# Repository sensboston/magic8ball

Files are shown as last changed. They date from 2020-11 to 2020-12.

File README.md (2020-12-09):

# "Magic 8 Ball" toy project
Arduino (ESP32-based) project for digital implementation of "Magic 8 ball" toy

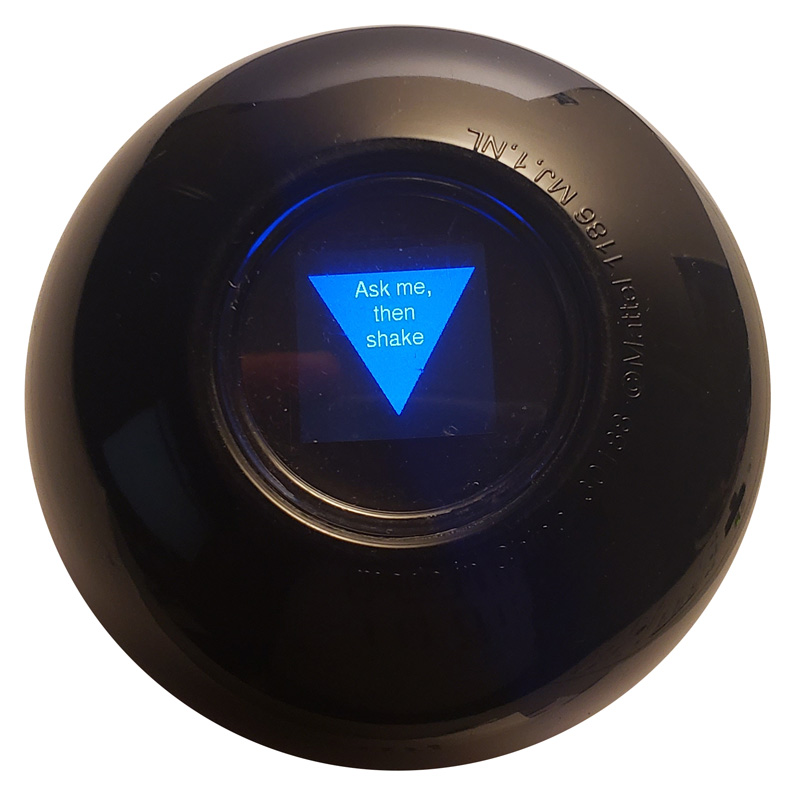
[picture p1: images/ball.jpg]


[](https://youtu.be/ifog76ZFch0)

## Features
This digital toy project offers many nice features unlike similar ones:
* multiple languages support
* synthetic voices
* realistic (or "realistic" :wink: ) animations
* gesture-based user interface
* "deep sleep" functionality (for better power consumption)

## Parts
Name | Link
------------ | -------------
**ESP32 development board** | [eBay](https://www.ebay.com/itm/Wireless-module-NodeMcu-v3-v2-ESP8266-D1MINI-Lua-WIFI-development-board-Rs4/283956013684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)
**TFT IPS Display 1.3'' 240x240** | [Amazon](https://www.amazon.com/gp/product/B088CQ4GPT/)
**DFPlayer Mini**| [eBay](https://www.ebay.com/itm/Useful-Mini-Mp3-Player-Module-DFPlayer-Micro-SD-TF-U-disk-for-Arduino-US/152513919098)
**16GB micro sdcard**| [Amazon](https://www.amazon.com/PNY-Performance-microSD-Memory-P-SDU16G4X5-MP/dp/B083VMR3PL/)
**MPU-6050 Accelerometer & Gyroscope Sensor** | [Amazon](https://www.amazon.com/Ximimark-MPU-6050-Accelerometer-Gyroscope-Converter/dp/B07M98PKT4)
**AAA battery holder** | [AliExpress](https://www.aliexpress.com/item/32719302709.html?spm=a2g0s.9042311.0.0.27424c4dsAHXA0)
**Short micro USB cable** | [eBay](https://www.ebay.com/itm/1M-Micro-USB-Extension-Charging-Data-Cable-Charger-Type-A-Male-To-Female/302277483939)
**Push button** | [Amazon](https://www.amazon.com/OFNMY-Self-Locking-Latching-Button-Switch/dp/B07NX7S9VV/)
**Original "Magic 8 ball" toy (for case)** | [Amazon](https://www.amazon.com/Mattel-Games-Magic-Ball-Retro/dp/B0149MC426/)

_Note: I believe, you can find better parts pricing on Ali/eBay etc. And I already had many of these parts before starting this project._

## Circuit
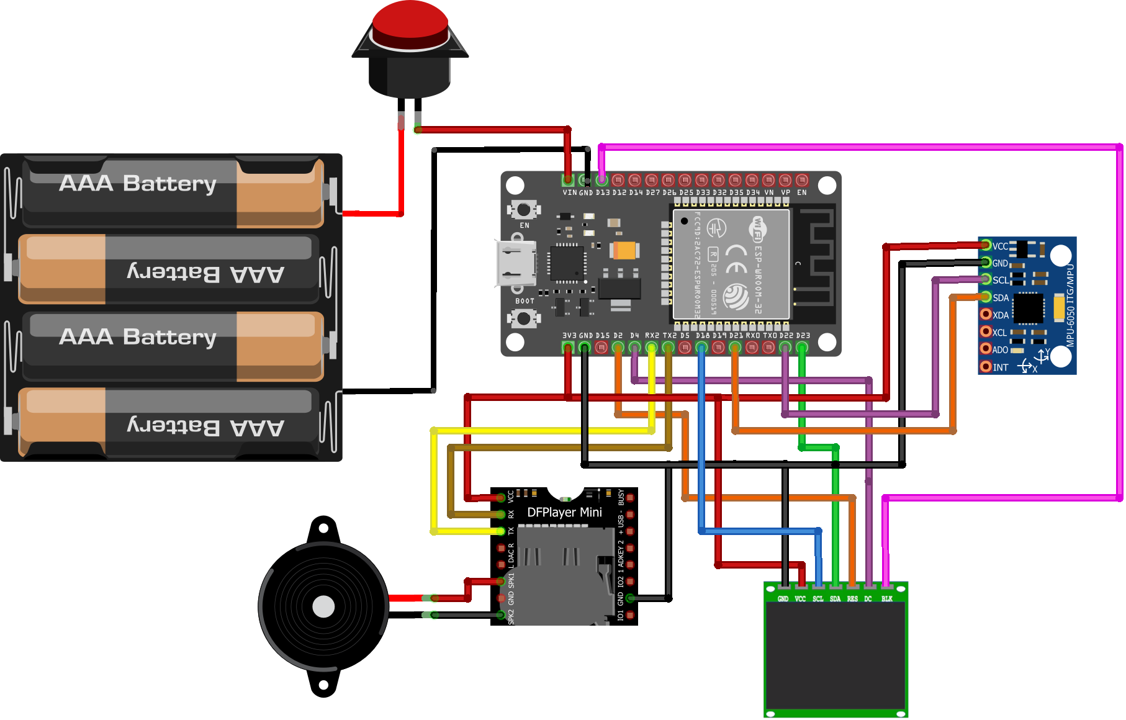
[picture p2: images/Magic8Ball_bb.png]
Circuit

### Zoomed ESP32 <-> Display connection (please note, different display type might require different connection scheme)
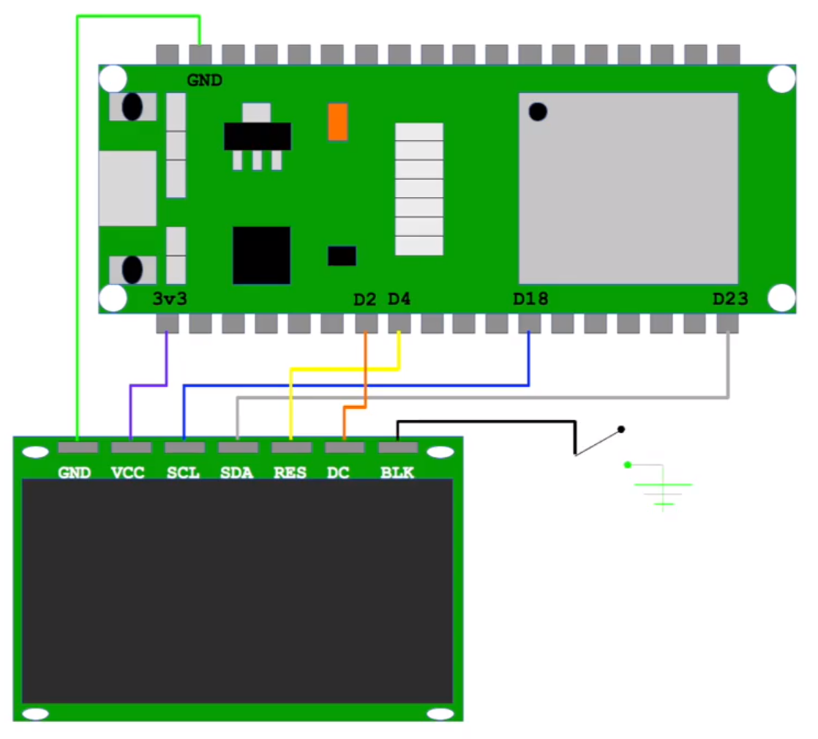
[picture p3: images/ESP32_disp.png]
Display

Also, here is [YouTube video](https://www.youtube.com/watch?v=HoZhgNcJjNA) for connecting ST7789-based displays to ESP32

_Note: you may want to add some resitors (for pulldown serial communication) or capacitors (for VCC). However in my case everything works "as is" :wink:_

## Building Arduino sketch
You should add a few extra libraries to Arduino IDE to build this project (see project includes)

For voice files generation I provide a small console utility **GenerateVoices**. Build it using VisualStudio (or download from Release section), and run from command prompt:

`
GenerateVoices.exe [full_path_to_Arduino_sketch]`

i.e.

`GenerateVoices.exe C:\repos\magic8ball\magic8ball.ino
`

then copy generated mp3 files to the root of sdcard.

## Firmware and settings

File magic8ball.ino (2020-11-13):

#define USE_DEEP_SLEEP
#define USE_SOUND

#include <TFT_eSPI.h>
#include <Wire.h>
#include <MPU6050.h>
#include <EEPROM.h>
#include <soc/rtc.h>
#include <HardwareSerial.h>
#include <DFRobotDFPlayerMini.h>

#define FONT_14
#ifdef FONT_14
#include "FontsRus/FreeSans14.h"
#else
#include "FontsRus/FreeSans12.h"
#endif

void drawSettingsMenu();
void drawSprite(TFT_eSprite *sprite);
void scaleSprite(TFT_eSprite *src, TFT_eSprite *dst, float scale, uint8_t alpha);
void prepareAnimation(bool isAppear);
char *utf8rus2(const char *source);
void checkInput();
void turnDisplay(bool isOn);
#define turnDisplayOn turnDisplay(true)
#define turnDisplayOff turnDisplay(false)

TFT_eSPI tft = TFT_eSPI();                      // TFT object
TFT_eSprite mainSprite = TFT_eSprite(&tft);     // main sprite object
TFT_eSprite scaledSprite = TFT_eSprite(&tft);   // scaled sprite object
#define TFT_BKLIGHT_PIN 13
int16_t screenTimeout = 30;
#define SCREEN_TIMEOUT ((int)screenTimeout * 1000)
#define SLEEP_TIMEOUT ((int)screenTimeout * 3 * 1000)
bool displayIsOn = true;

enum GAME_STATES
{
    APPEARANCE,
    SHOW,
    DISAPPEARANCE,
    SETTINGS
};
GAME_STATES gameState;

// Prediction ranges:
//      realistic:   1 - 15
//        optimistic:  1 - 11
//      pessimistic: 6 - 15
const int predRanges[3][2] { {1, 16}, {1, 12}, {6, 16} };

#define NUM_LANGUAGES 3
#define NUM_PHRASES 16
const String languages[NUM_LANGUAGES][NUM_PHRASES][3] 
{
    // 0: English
    {
        {"Ask me,", "then", "shake"},  
        
        {"It is", "certain", ""},       // 1
        {"Certainly", "", ""},          // 2
        {"Without", "a doubt", ""},     // 3
        {"You", "may rely", "on it"},   // 4
        {"As", "I see it,", "yes" },    // 5
        {"Most", "likely", "" },        // 6
        {"Yes", "", ""},                // 7
        {"Can't", "predict", ""},       // 8        
        {"Ask", "again", "later"},      // 9
        {"Not", "sure", ""},            // 10
        {"My", "reply is", "no"},       // 11
        {"Very", "doubtful", ""},       // 12
        {"No", "", ""},                 // 13
        {"No", "chance", ""},           // 14
        {"No", "way", ""},              // 15
    },
    // 1: Russian
    {
        {"Спроси и", "встряхни", ""},
        
        {"Это", "точно!", ""},          // 1
        {"Точно", "", ""},              // 2
        {"Без", "сомнения", ""},        // 3
        {"Ты", "можешь", "так считать"},// 4
        {"Как", "я вижу,", "да"},       // 5
        {"Скорее", "всего", ""},        // 6
        {"Да", "", ""},                 // 7
        {"Не", "могу", "сказать"},      // 8        
        {"Спроси", "позже", ""},        // 9
        {"Не", "уверена", ""},          // 10
        {"Мой", "ответ:", "нет"},       // 11
        {"Вряд ли", "", ""},            // 12
        {"Нет", "", ""},                // 13
        {"Без", "шансов", ""},          // 14
        {"Никак", "не выйдет", ""},     // 15
    },
    // 2: Spanish
    {
        {"Pregunte,", "luego", "agite"},    
        
        {"Es", "cierto", ""},                   // 1
        {"¡Desde", "luego!", ""},               // 2
        {"Sin", "duda", ""},                    // 3
        {"Puedes", "confiar", "en ello"},       // 4
        {"Como yo", "lo veo,", "sí"},           // 5
        {"Más", "probable", ""},                // 6
        {"si", "", ""},                         // 7
        {"No puedo", "predecir", ""},           // 8
        {"Pregunta de", "nuevo más", "tarde"},  // 9
        {"No estoy", "seguro", ""},             // 10
        {"Mi", "respuesta", "es no"},           // 11
        {"Muy", "dudoso", ""},                  // 12
        {"No", "", ""},                         // 13
        {"Ninguna", "posibilidad", ""},         // 14
        {"De ninguna", "manera", ""},           // 15
    }
};

#define NUM_MENUS 4
const String menuTitles[NUM_MENUS] = { "Choose language:", "Screen timeout:", "Sound volume:", "Prediction kind:" };
const String menuChoices[NUM_MENUS][NUM_LANGUAGES] = { 
    { "English", "Russian", "Spanish" },
    { "30 sec", "45 sec", "60 sec" },
    { "Loud", "Quiet", "No sound" },
    { "Realistic", "Optimistic", "Pessimistic" }
};

byte lang = 0, range = 0;
int16_t soundVolume = 30;
byte phraseIdx = 0, currMenu = 0, currChoice = 0;
bool doRandSeed = true;

#define MIN_SCALE 0.1
#define MAX_SCALE 0.98
const int16_t animSteps = 24;
const int16_t tr_side = 206;
float angle, d_angle = 1.0, scale = 1.0, d_scale = 1.0 / animSteps;
int rotate_dir = 1;
unsigned long startShowTime, startHideTime, displayOffTime;
int d_x, d_y, showCount;

MPU6050 mpu;

enum INPUT_STATES 
{
    NONE,
    SHAKE,
    UP,
    DOWN,
    LEFT,
    RIGHT
};

float ax, ay, az, gx, gy, gz, avg_ax, avg_ay, avg_az, avg_gx, avg_gy, avg_gz;
float min_ax, max_ax, min_ay, max_ay, min_az, max_az;
int16_t x, y, z, checkInputCount, shakeCount = 0;
unsigned long measTime;
INPUT_STATES inputState = NONE;

#define INPUT_INTERVAL 500
int checkInputInterval = INPUT_INTERVAL;

#ifdef USE_SOUND
bool playerReady = false;
HardwareSerial softSerial(2);
DFRobotDFPlayerMini player;
#endif

void setup() 
{
    Serial.begin(115200);

    // Read settings values from EEPROM
    EEPROM.begin(16);
    lang = EEPROM.read(0);
    if (lang >= NUM_LANGUAGES) lang = 0;
    screenTimeout = 30 + (EEPROM.read(1)*15);
    if (screenTimeout > 60) screenTimeout = 30;
    soundVolume = (2-EEPROM.read(2))*15;
    if (soundVolume > 30) soundVolume = 30;
    range = EEPROM.read(3);
    if (range > 2) range = 0;

    // MPU initialization
    Wire.begin();

    mpu.initialize();
    
    mpu.setInterruptDrive(0);                       // Set interrupt drive mode (0=push-pull, 1=open-drain)
    mpu.setInterruptMode(1);                        // Set interrupt mode (0=active-high, 1=active-low)
    mpu.setInterruptLatch(0);                       // Interrupt pulses when triggered instead of remaining on until cleared
    mpu.setDHPFMode(MPU6050_DHPF_5);
    mpu.setMotionDetectionThreshold(2);             // Motion detection acceleration threshold. 1LSB = 2mg.
    mpu.setMotionDetectionDuration(50);             // Motion detection event duration in ms
    mpu.setFreefallDetectionCounterDecrement(1);    // Set free fall detection counter decrement
    mpu.setMotionDetectionCounterDecrement(1);      // Set motion detection counter decrement
    mpu.setIntMotionEnabled(false);                 // Set interrupt enabled status

    checkInputInterval = INPUT_INTERVAL;
    checkInputCount = shakeCount = 0; 
    avg_ax = avg_ay = avg_az = avg_gx = avg_gy = avg_gz = az = 0;
    min_ax = min_ay = min_az = 5000;
    max_ax = max_ay = max_az = -5000;
    checkInput();

    // Initialize TFT display
    tft.begin();  
    tft.fillScreen(TFT_BLACK);
    turnDisplayOn;

    // Calculate triangle points
    int w = tft.width();
    float tr_h = (tr_side * 1.732) / 2.0;
    d_y = (w - tr_h) / 2; 
    d_x = (w - tr_side) / 2;
    
    // Set pivot to the middle of the screen
    tft.setPivot(w/2, w/2);

    // Create sprite
    mainSprite.createSprite(w, w);
    mainSprite.setTextColor(TFT_WHITE);
#ifdef FONT_14    
    mainSprite.setFreeFont(&FreeSans14pt8b);
#else
    mainSprite.setFreeFont(&FreeSans12pt8b);
#endif    
    mainSprite.setAttribute(UTF8_SWITCH, false);

    // We should start from "intro" message
    phraseIdx = 0;
    angle = 0; scale = 0.1;    
    drawSprite(&mainSprite);

#ifdef USE_SOUND
    // Initialize software serial port (speed, type, RX & TX pins)
    softSerial.begin(9600, SERIAL_8N1, 16, 17);  
    delay(100);  

    // Initialize DFPlayerMini
    if (player.begin(softSerial, false, true)) 
    {  
        playerReady = true;
        //Serial.println("Player is ready!");
        // Set serial communictaion time out 500ms
        player.setTimeOut(500);
        player.outputDevice(DFPLAYER_DEVICE_SD);
        player.volume(soundVolume);
    }
#endif    

    prepareAnimation(true);
    gameState = APPEARANCE;
    inputState = NONE;
    startHideTime = millis();
}

void loop() 
{
    if (checkInputCount++ > checkInputInterval)
    {
        checkInputCount = 0;
        checkInput();

        if (ax-avg_ax > 10 || ay-avg_ay > 10 || az-avg_az > 10)
        {
            if (!displayIsOn)
            {
                turnDisplayOn;
                inputState = NONE;
            }
            else startHideTime = millis();
        }

        // Check triple shake
        if (displayIsOn && inputState == SHAKE)
        {
            if (shakeCount >= 4)
            {
                currMenu = shakeCount = 0;
                currChoice = lang;
                gameState = SETTINGS;
                inputState = NONE;
                drawSettingsMenu();
                delay(500);
                startHideTime = millis();
            }
        }
    }

    // Handle game states only when display is on
    if (displayIsOn)
    {
        // Reset multiple shake counter
        if (millis()-measTime > 1500) shakeCount = 0;
        
        switch (gameState)
        {
            case SETTINGS:
                if (millis()-startHideTime > SCREEN_TIMEOUT) turnDisplayOff;
                if (inputState != NONE)
                {
                    if (inputState == SHAKE)
                    {
                        phraseIdx = 0; 
                        drawSprite(&mainSprite);
                        mainSprite.pushSprite(0, 0);
                        gameState = SHOW;
                        delay(500);
                    }
                    else
                    {
                        // Switch selection
                        if (inputState == UP || inputState == DOWN)
                        {
                            if (inputState == UP) currChoice--; else if (inputState == DOWN) currChoice++;
                            if (currChoice < 0) currChoice = NUM_LANGUAGES-1; else if (currChoice >= NUM_LANGUAGES) currChoice = 0;

                            // Save new setting
                            EEPROM.write(currMenu, currChoice);
                            EEPROM.commit();
                            
                            if (currMenu == 0) lang = currChoice;
                            else if (currMenu == 1) screenTimeout = 30 + (currChoice*15);
                            else if (currMenu == 2)
                            {
                                soundVolume = (2-currChoice) * 15;
#ifdef USE_SOUND                                
                                player.volume(soundVolume);
#endif                                
                            }
                            else if (currMenu == 3) range = currChoice;
                            
                        }
                        else
                        {
                            if (inputState == LEFT) currMenu--; else if (inputState == RIGHT) currMenu++;
                            if (currMenu < 0) currMenu = NUM_MENUS-1; else if (currMenu >= NUM_MENUS) currMenu = 0;
                            
                            if (currMenu == 0) currChoice = lang;
                            else if (currMenu == 1) currChoice = (screenTimeout-30) / 15;
                            else if (currMenu == 2) currChoice = 2 - (soundVolume / 15);
                            else if (currMenu == 3) currChoice = range;
                        }
    
                        drawSettingsMenu();
                        delay(250);                    
                    }
                    shakeCount = 0;
                    startHideTime = millis();                
                }
                break;
            
            case APPEARANCE:
                if (millis()-startHideTime > 1000)
                {
#ifdef USE_SOUND
                    if (playerReady && scale <= MIN_SCALE + 0.1 && soundVolume > 0)
                    {
                        player.play(lang*NUM_PHRASES + phraseIdx + 1);
                    }
#endif
                    scaleSprite(&mainSprite, &scaledSprite, scale, scale * 210);
                    scaledSprite.pushRotated(rotate_dir > 0 ? angle : 360-angle);
                    angle -= d_angle;
                    scale += d_scale;
                    if (scale > 0.98)
                    {
                        mainSprite.pushSprite(0, 0);
                        startShowTime = millis();
                        gameState = SHOW;
                    }
                }
                break;
    
            case SHOW:
                // Provide new "divination" on shake
                if (inputState == SHAKE)
                {
                    // select random prediction, based on range
                    phraseIdx = random(predRanges[range][0], predRanges[range][1]);
                    prepareAnimation(false);
                    gameState = DISAPPEARANCE;
                }
                // Turn off display after 25 seconds
                else if (millis() - startHideTime > SCREEN_TIMEOUT) turnDisplayOff;
                break;
    
            case DISAPPEARANCE:
                scaleSprite(&mainSprite, &scaledSprite, scale, scale * 180);
                scale -= d_scale;
                if (scale < 0.95) angle += d_angle;            
                scaledSprite.pushRotated(rotate_dir > 0 ? angle : 360-angle);
    
                if (scale < 0.05)
                {
                    // Clear screen
                    tft.fillScreen(TFT_BLACK);
                    
                    // Draw sprite
                    drawSprite(&mainSprite);
    
                    gameState = APPEARANCE;
                    prepareAnimation(true);
                    startHideTime = millis();
                }
                break;    
        }
    
        // Always reset input state to NONE
        inputState = NONE;            
    }
    // We can't use light or deep sleep modes now, let's use delay()
    else
    {
        delay(10);
#ifdef USE_DEEP_SLEEP
        if (millis()-displayOffTime > SLEEP_TIMEOUT)
        {
#ifdef USE_SOUND
            if (playerReady) player.sleep();
#endif            
            // Put ST7789 TFT controller to sleep (dispaly is already off)
            tft.writecommand(0x10);
            // Enable motion interrupt on MPU6050
            mpu.setIntMotionEnabled(true);
            // Enable external source wake up for ESP32 dev. board
            esp_sleep_enable_ext0_wakeup(GPIO_NUM_14, 0);
            delay(100);
            esp_deep_sleep_start();
        }
#endif        
    }
}

// Toggle display, backlight and CPU clock
void turnDisplay(bool isOn)
{
    displayIsOn = isOn;

    // Turn on/off display
    tft.writecommand(isOn ? 0x29 : 0x28);
    delay(10);
    
    // Turn on/off backlight
    if (isOn)
    {
        // Disable holding pin state for backlight pin
        gpio_hold_dis(GPIO_NUM_13);
        pinMode(TFT_BKLIGHT_PIN, INPUT); 
    }
    else
    {
        pinMode(TFT_BKLIGHT_PIN, OUTPUT);
        // Enable holding pin state during sleep for backlight pin
        gpio_hold_en(GPIO_NUM_13);
    }
    // Set clock
    rtc_clk_cpu_freq_set(isOn ? RTC_CPU_FREQ_240M : RTC_CPU_FREQ_80M);
    checkInputInterval = isOn ? INPUT_INTERVAL : 2;

    if (isOn) startHideTime = millis();
    else displayOffTime = millis();
}

// Draw settings menu
void drawSettingsMenu()
{
    int w = mainSprite.width();
    int lineHeight = 32;
    int startY = lineHeight*2;
    mainSprite.fillSprite(TFT_BLACK);
    mainSprite.drawString(menuTitles[currMenu], 4, 2);
    for (int i=0; i<NUM_LANGUAGES; i++)
    {
        if (i == currChoice) mainSprite.fillRoundRect(2, startY + (i*lineHeight), w-2, lineHeight, 2, TFT_BLUE);
        mainSprite.drawString(menuChoices[currMenu][i], 20, startY + (i*lineHeight));
    }
    mainSprite.pushSprite(0, 0);
}

// Prepare animation
void prepareAnimation(bool isAppear)
{
    // Rotation direction 
    rotate_dir = (random(0,2) == 1 ? 1 : -1);
    angle = isAppear ? random(45, 165) : 0;
    d_angle = isAppear ? angle / animSteps : (random(35, 155) / animSteps);

    scale = isAppear ? MIN_SCALE : MAX_SCALE;
    d_scale = 0.98 / (animSteps + 3);
    startHideTime = startShowTime = millis();
}

// Draws "prediction" triangle with text
void drawSprite(TFT_eSprite *sprite) 
{
    char phrases[3][50];
    int numPhrases = 0;

    int w = sprite->width();
    int h = w;
    int c = w/2;
    sprite->setPivot(c, c);

    for (int i = 0; i < 3; i++)
    {
        strcpy(phrases[i], utf8rus2(languages[lang][phraseIdx][i].c_str()));
        if (strlen(phrases[i]) > 0) numPhrases++;
    }  

    sprite->fillSprite(TFT_BLACK);

    int y = c-d_x;

    // Long first word and more than one word in sentence
    if (strlen(phrases[0]) >= 5 && numPhrases > 1)
    {
        sprite->fillTriangle(d_x, d_y, w-d_x, d_y, c, h-d_y, TFT_BLUE);
        if (numPhrases == 3) y = h/5-d_y; else y = h/4-d_y;
    }
    // Short first word or only one word
    else 
    {
        sprite->fillTriangle(d_x, h-d_y, c, d_y, w-d_x, h-d_y, TFT_BLUE);
        if (numPhrases == 2) y = h/3+d_x; else if (numPhrases == 3) y = h/4+d_x;
    }

    for (int i = 0; i < numPhrases; i++)
        sprite->drawString(phrases[i], c - (sprite->textWidth(phrases[i]) / 2), i * sprite->fontHeight()+y+d_x);
}

// Sprite scaling with linear interpolation
// TODO: refactor for more efficient, elegant and faster code
#define RGB(r,g,b) (uint16_t) ( ((r << 11) & 0xF800) | ((g << 5) & 0x7E0) |  (b & 0x1F) )
#define Rc(px) (uint16_t)  (px >> 11)
#define Gc(px) (uint16_t) ((px & 0x7E0) >> 5)
#define Bc(px) (uint16_t)  (px & 0x1F)
void scaleSprite(TFT_eSprite *src, TFT_eSprite *dst, float scale, uint8_t alpha = 255)
{
    uint16_t x, y, w, h, r, g, b;
    uint16_t A, B, C, D;

    uint16_t newWidth = (uint16_t)(src->width() * scale);
    uint16_t newHeight = (uint16_t)(src->height() * scale);
    float ratio = ((float)(src->width() - 1)) / newWidth;

    dst->deleteSprite();
    dst->createSprite(newWidth, newHeight);

    for (int i = 0; i < newHeight; i++)
    {
        for (int j = 0; j < newWidth; j++)
        {
            x = (uint16_t)(ratio * j);
            y = (uint16_t)(ratio * i);
            w = (uint16_t)(ratio * j) - x;
            h = (uint16_t)(ratio * i) - y;

            A = src->readPixel(x, y);
            B = src->readPixel(x + 1, y);
            C = src->readPixel(x, y + 1);
            D = src->readPixel(x + 1, y + 1);

            r = (uint16_t)(Rc(A) * (1 - w) * (1 - h) + Rc(B) * (w) * (1 - h) + Rc(C) * (h) * (1 - w) + Rc(D) * (w * h));
            g = (uint16_t)(Gc(A) * (1 - w) * (1 - h) + Gc(B) * (w) * (1 - h) + Gc(C) * (h) * (1 - w) + Gc(D) * (w * h));
            b = (uint16_t)(Bc(A) * (1 - w) * (1 - h) + Bc(B) * (w) * (1 - h) + Bc(C) * (h) * (1 - w) + Bc(D) * (w * h));

            // If no alpha blending, just draw the pixel
            if (alpha == 255) dst->drawPixel(j, i, RGB(r, g, b));
            // Otherwise, draw with alpha blending
            else dst->drawPixel(j, i, dst->alphaBlend(alpha, RGB(r, g, b), TFT_BLACK));
        }
    }
}

#define MAX_STR_LEN 30
char target[MAX_STR_LEN + 1] = "";
char *utf8rus2(const char *source)
{
    int i, j, k;
    unsigned char n;
    char m[2] = { '0', '\0' };
    strcpy(target, ""); k = strlen(source); i = j = 0;
    while (i < k) 
    {
        n = source[i++];
        if (n >= 127) 
        {
            switch (n) 
            {
                case 208: 
                    n = source[i]; i++;
                    break;
            
                case 209: 
                    n = source[i]; i++;
                    break;
            } 
        } 

        m[0] = n; strcat(target, m);
        j++; if (j >= MAX_STR_LEN) break;
    }
    return target;
}

#define WINDOW_SIZE 30

float approxAverage (float avg, float input) 
{
    avg -= avg / WINDOW_SIZE;
    avg += input / WINDOW_SIZE;
    return avg;
}

void checkInput()
{
    int16_t a_x, a_y, a_z, g_x, g_y, g_z;
    mpu.getMotion6(&a_x, &a_y, &a_z, &g_x, &g_y, &g_z);

    if (doRandSeed)
    {
        randomSeed(a_x+a_y+a_z);
        doRandSeed = false;
    }

    ax = a_x / 100; 
    ay = a_y / 100; 
    az = a_z / 100;
    gx = g_x / 100; 
    gy = g_y / 100; 
    gz = g_z / 100;

    // Calculate running averages
    avg_ax = approxAverage(avg_ax, ax);
    avg_ay = approxAverage(avg_ay, ay);
    avg_az = approxAverage(avg_az, az);
    avg_gx = approxAverage(avg_gx, gx);
    avg_gy = approxAverage(avg_gy, gy);
    avg_gz = approxAverage(avg_gz, gz);

    if (ax > max_ax) max_ax = ax; else if (ax < min_ax) min_ax = ax;
    if (ay > max_ay) max_ay = ay; else if (ay < min_ay) min_ay = ay;
    if (az > max_az) max_az = az; else if (az < min_az) min_az = az;

    // Shake detection
    if (max_ax-min_ax > 500 || max_ay-min_ay > 500 || max_az-min_az > 500)
    {
        min_ax = min_ay = min_az = 5000;
        max_ax = max_ay = max_az = -5000;
        shakeCount++;
        inputState = SHAKE;
        measTime = millis();        
    }
    // Up/down, left/right detection (for menu control)
    else if (millis()-measTime > 1000)
    {
        int16_t dx = (gx-avg_gx) / 5; 
        int16_t dy = (gy-avg_gy) / 5; 
        int16_t dz = (gz-avg_gz) / 5;

        if (abs(dx) > 40 && abs(dy) > 40) inputState = (dx < 0) ? DOWN : UP;
        else if (abs(dz) > 20) inputState = (dz < 0) ? LEFT : RIGHT;

        if (inputState != NONE)
        {
            gx = gy = gz = avg_gx = avg_gy = avg_gz = 0;
            measTime = millis();
        }
    }
}

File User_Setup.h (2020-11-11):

//                            USER DEFINED SETTINGS
//   Set driver type, fonts to be loaded, pins used and SPI control method etc
//
//   See the User_Setup_Select.h file if you wish to be able to define multiple
//   setups and then easily select which setup file is used by the compiler.
//
//   If this file is edited correctly then all the library example sketches should
//   run without the need to make any more changes for a particular hardware setup!
//   Note that some sketches are designed for a particular TFT pixel width/height


// ##################################################################################
//
// Section 1. Call up the right driver file and any options for it
//
// ##################################################################################

// Define STM32 to invoke optimised processor support (only for STM32)
//#define STM32

// Defining the STM32 board allows the library to optimise the performance
// for UNO compatible "MCUfriend" style shields
//#define NUCLEO_64_TFT
//#define NUCLEO_144_TFT

// STM32 8 bit parallel only:
// If STN32 Port A or B pins 0-7 are used for 8 bit parallel data bus bits 0-7
// then this will improve rendering performance by a factor of ~8x
//#define STM_PORTA_DATA_BUS
//#define STM_PORTA_DATA_BUS

// Tell the library to use 8 bit parallel mode (otherwise SPI is assumed)
//#define TFT_PARALLEL_8_BIT

// Display type -  only define if RPi display
//#define RPI_DISPLAY_TYPE // 20MHz maximum SPI

// Only define one driver, the other ones must be commented out
//#define ILI9341_DRIVER
//#define ST7735_DRIVER      // Define additional parameters below for this display
//#define ILI9163_DRIVER     // Define additional parameters below for this display
//#define S6D02A1_DRIVER
//#define RPI_ILI9486_DRIVER // 20MHz maximum SPI
//#define HX8357D_DRIVER
//#define ILI9481_DRIVER
//#define ILI9486_DRIVER
//#define ILI9488_DRIVER     // WARNING: Do not connect ILI9488 display SDO to MISO if other devices share the SPI bus (TFT SDO does NOT tristate when CS is high)
//#define ST7789_DRIVER      // Full configuration option, define additional parameters below for this display
#define ST7789_2_DRIVER    // Minimal configuration option, define additional parameters below for this display
//#define R61581_DRIVER
//#define RM68140_DRIVER
//#define ST7796_DRIVER

// Some displays support SPI reads via the MISO pin, other displays have a single
// bi-directional SDA pin and the library will try to read this via the MOSI line.
// To use the SDA line for reading data from the TFT uncomment the following line:

#define TFT_SDA_READ      // This option is for ESP32 ONLY, tested with ST7789 display only

// For ST7789 and ILI9341 ONLY, define the colour order IF the blue and red are swapped on your display
// Try ONE option at a time to find the correct colour order for your display

#define TFT_RGB_ORDER TFT_RGB  // Colour order Red-Green-Blue
//  #define TFT_RGB_ORDER TFT_BGR  // Colour order Blue-Green-Red

// For M5Stack ESP32 module with integrated ILI9341 display ONLY, remove // in line below

// #define M5STACK

// For ST7789, ST7735 and ILI9163 ONLY, define the pixel width and height in portrait orientation
// #define TFT_WIDTH  80
// #define TFT_WIDTH  128
#define TFT_WIDTH  240 // ST7789 240 x 240 and 240 x 320
// #define TFT_HEIGHT 160
// #define TFT_HEIGHT 128
#define TFT_HEIGHT 240 // ST7789 240 x 240
// #define TFT_HEIGHT 320 // ST7789 240 x 320

// For ST7735 ONLY, define the type of display, originally this was based on the
// colour of the tab on the screen protector film but this is not always true, so try
// out the different options below if the screen does not display graphics correctly,
// e.g. colours wrong, mirror images, or tray pixels at the edges.
// Comment out ALL BUT ONE of these options for a ST7735 display driver, save this
// this User_Setup file, then rebuild and upload the sketch to the board again:

// #define ST7735_INITB
// #define ST7735_GREENTAB
// #define ST7735_GREENTAB2
// #define ST7735_GREENTAB3
// #define ST7735_GREENTAB128    // For 128 x 128 display
// #define ST7735_GREENTAB160x80 // For 160 x 80 display (BGR, inverted, 26 offset)
// #define ST7735_REDTAB
// #define ST7735_BLACKTAB
// #define ST7735_REDTAB160x80   // For 160 x 80 display with 24 pixel offset

// If colours are inverted (white shows as black) then uncomment one of the next
// 2 lines try both options, one of the options should correct the inversion.

// #define TFT_INVERSION_ON
// #define TFT_INVERSION_OFF


// ##################################################################################
//
// Section 2. Define the pins that are used to interface with the display here
//
// ##################################################################################

// If a backlight control signal is available then define the TFT_BL pin in Section 2
// below. The backlight will be turned ON when tft.begin() is called, but the library
// needs to know if the LEDs are ON with the pin HIGH or LOW. If the LEDs are to be
// driven with a PWM signal or turned OFF/ON then this must be handled by the user
// sketch. e.g. with digitalWrite(TFT_BL, LOW);

// #define TFT_BL   32            // LED back-light control pin
// #define TFT_BACKLIGHT_ON HIGH  // Level to turn ON back-light (HIGH or LOW)



// We must use hardware SPI, a minimum of 3 GPIO pins is needed.
// Typical setup for ESP8266 NodeMCU ESP-12 is :
//
// Display SDO/MISO  to NodeMCU pin D6 (or leave disconnected if not reading TFT)
// Display LED       to NodeMCU pin VIN (or 5V, see below)
// Display SCK       to NodeMCU pin D5
// Display SDI/MOSI  to NodeMCU pin D7
// Display DC (RS/AO)to NodeMCU pin D3
// Display RESET     to NodeMCU pin D4 (or RST, see below)
// Display CS        to NodeMCU pin D8 (or GND, see below)
// Display GND       to NodeMCU pin GND (0V)
// Display VCC       to NodeMCU 5V or 3.3V
//
// The TFT RESET pin can be connected to the NodeMCU RST pin or 3.3V to free up a control pin
//
// The DC (Data Command) pin may be labeled AO or RS (Register Select)
//
// With some displays such as the ILI9341 the TFT CS pin can be connected to GND if no more
// SPI devices (e.g. an SD Card) are connected, in this case comment out the #define TFT_CS
// line below so it is NOT defined. Other displays such at the ST7735 require the TFT CS pin
// to be toggled during setup, so in these cases the TFT_CS line must be defined and connected.
//
// The NodeMCU D0 pin can be used for RST
//
//
// Note: only some versions of the NodeMCU provide the USB 5V on the VIN pin
// If 5V is not available at a pin you can use 3.3V but backlight brightness
// will be lower.


// ###### EDIT THE PIN NUMBERS IN THE LINES FOLLOWING TO SUIT YOUR ESP8266 SETUP ######
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

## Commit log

2020-11-11 rearrange images
    [Magic8Ball.fzz]
2020-11-13 fixed small mistakes in the schematics image added menu option fixed (partially, there are some things to do) motion detection part
    [magic8ball.ino]
